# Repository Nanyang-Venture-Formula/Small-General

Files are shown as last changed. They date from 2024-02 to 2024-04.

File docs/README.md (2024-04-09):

# Small General (Rev 4.1)

This repository contains all documents regarding the Small General board.

### Shortcuts
- [Schematics](#Schematics)
- [Assembly](#Assembly)
- [Renders](#Renders)
- [Bom](#Bom)

---

## Schematics



## Assembly




## Renders

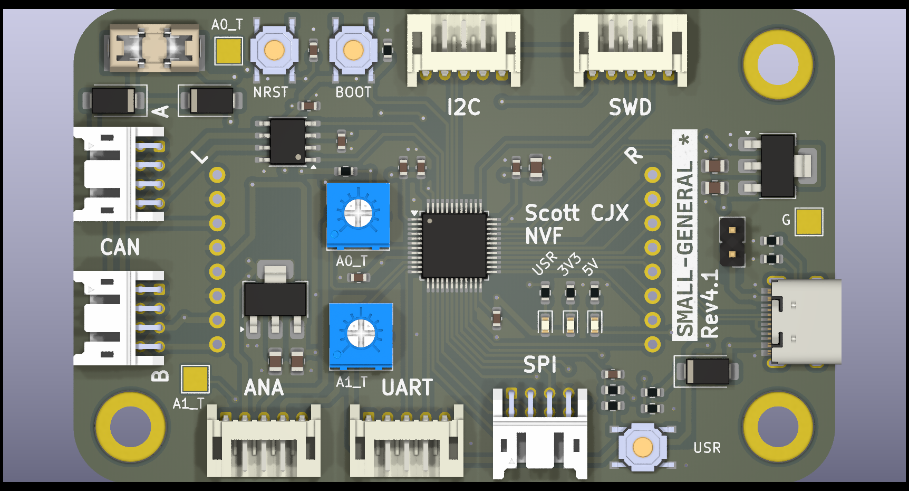
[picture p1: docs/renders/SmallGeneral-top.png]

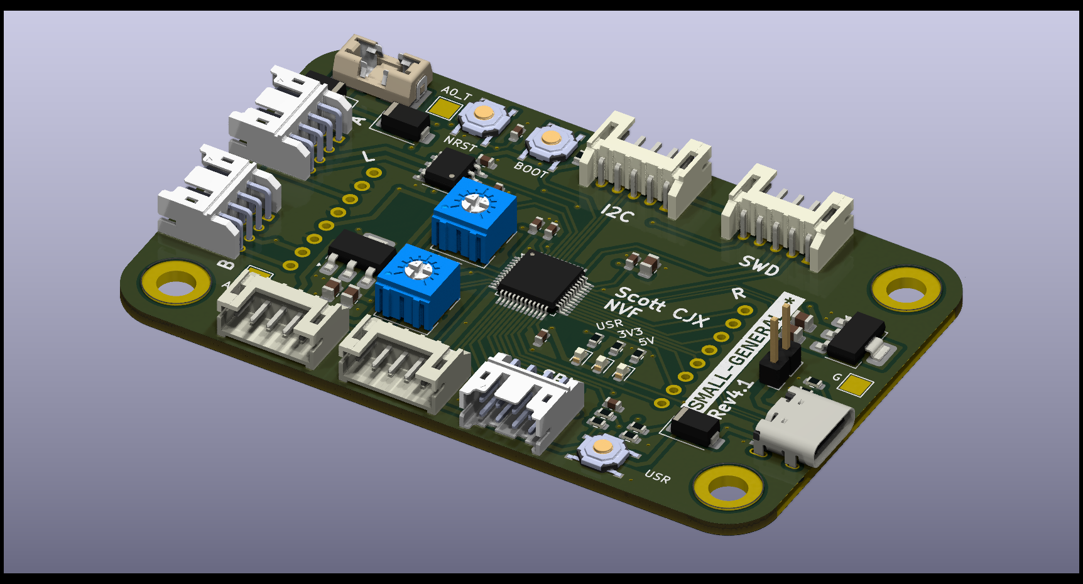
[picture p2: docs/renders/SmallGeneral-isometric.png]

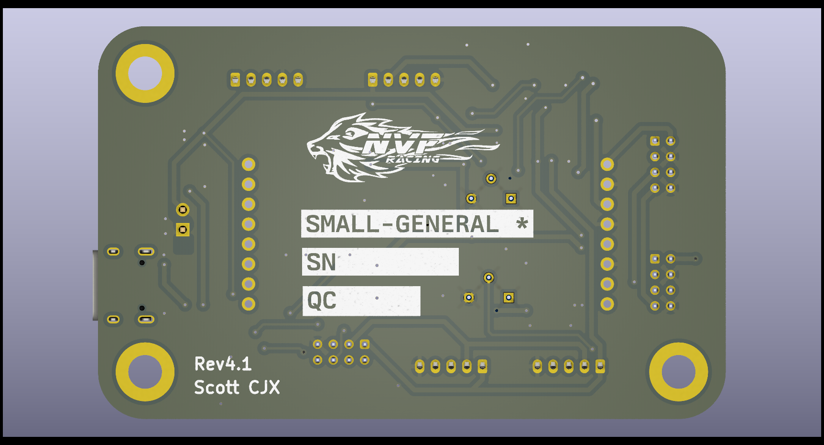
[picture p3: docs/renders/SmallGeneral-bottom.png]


## Bom

[Interactive BOM](./ibom/ibom)

[BOM](./bom/SmallGeneral-BOM.csv)

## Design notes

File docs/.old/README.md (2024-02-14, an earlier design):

# Overview

The Small General is a STM32 based development board that boast a 48MHz Cortex-M0 STM32F072 Microcontroller and breaks out interfaces that a user would usually use when prototyping or for use in small spaces.

### Quick Links

- [Renders](./Renders.md "Renders")
- [Technical](./Technical.md "Technical")

## Form Factor

The Small General is 50mm x 80mm in size.

There are 4 x M4 screw holes (padded top and bottom; connected to ground) that are 6mm x 6mm from the corners of the boards 50mm x 80mm dimensions.

There are 3mm fillets at all 4 corners of the board.

## Features

1. STM32F072CBT6 Microcontroller.
2. USB C (Power & Data)
3. Integrated CanBus. (Multiple Connections)
4. Dual Voltage Regulators for stable 3.3V and 5V supply ( $V_{MAX}$: 20V)
5. Dual trim potentiometers to scale down analog signals before processing + easily accessible testpoints to probe using multimeters.
6. NRST, BOOT0 buttons
7. LED Indicators for 3v3 Power, 5v power
8. Programmble User button and LED

## 5 Pin Connectors:

| Interface | Pin A | Pin B |
| --- | --- | --- |
| ADC | PA0 (A0) | PA1 (A1) |
| UART (UART2) | PA2 (TX) | PA3 (RX) |
| I2C | PB6 (SCL) | PB7 (SDA) |
| SW Debug (SWD) | PA13 (SWDIO) | PA14 (SWCLK) |

Compatible connectors (01x05 Styled - 2.00mm)

- JST PH S5B [Horizontal] (Refer to Parts)
- JST PH B5B [Vertical] (Refer to Parts)

### 8 Pin Connectors:

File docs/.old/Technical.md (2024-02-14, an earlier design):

# Technical

Technical components of the Small General

# LEDs

Calculations for Current Limiting Resistors (CLRs):

Taking into consideration the LED's $V_{F}$ and $I_{F}$, and input Voltage $V_{IN}$:

we can calculate the CLR with the formula $R = \dfrac{(V_{IN}-V_{F})}{I_{F}}$.

### User LED

| Factor | Value |
| --- | ----- |
| $V_{IN}$ | 3.3V  |
| $V_{F}$  | 2.5V  |
| $I_{F}$  | 4mA |

$R = \dfrac{(V_{IN}-V_{F})}{I_{F}} = \dfrac{(3.3-2.5)}{0.004} = 200 \Omega$

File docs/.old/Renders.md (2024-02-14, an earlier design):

# Renders

There are serveral styles of interconnect connectors for the Small General.

- Stacking

  - (Top Female, Bottom Male): Stacking TFBM
- Male Headers

  - (Top Male, Bottom None): TMBN
  - (Top None, Bottom Male): TNBM
- Female Sockets

  - (Top Female, Bottom None): TFBN
  - (Top None, Bottom Female): TNBF
- None

  - (Top None, Bottom None): TNBN

## Stacking TFBM (Top Female, Bottom Male)

TFBM-F

TFBM-I

## TMBN (Top Male, Bottom None)TMBN-F

## TNBN (Top None, Bottom None)

TNBN-F

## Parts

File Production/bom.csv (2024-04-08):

Designator | Footprint | Quantity | Value | LCSC Part #
C101 | 0805 | 1 | 4u7 | C1779
C102, C103, C104, C105, C106, C107, C108, C109, C110 | 0603 | 9 | 100n | C14663
C111, C112, C113, C114 | 0805 | 4 | 2u2 | C377773
D101 | 0603 | 1 | GREEN | C434423
D102 | 0603 | 1 | RED | C2286
D103 | 0603 | 1 | BLUE | C965807
D104, D105, D106 | D_SMA | 3 | SS14 | C2480
F101 | FUSE-Littelfuse_Nano2_154x | 1 | Fuse | C206919
J101 | USBC_HRO_TYPE-C-31-M-12 | 1 | USB_C | C165948
JP101 | PinHeader_1x02_P2.54mm_Vertical | 1 | Jumper_2_Open | -
R101, R102, R103, R110 | 0603 | 4 | 10k | C25804
R104, R111 | 0603 | 2 | 1k | C21190
R105, R106, R107 | 0603 | 3 | 300 | C23025
R108, R109 | 0603 | 2 | 5k1 | C23186
RV101, RV102 | RV_Bourns_3362 | 2 | 10k | C58159
SG101 | Small-General Actual | 1 | ~ | -
SW101, SW102, SW103 | PushBtn_TS-1187A-B-A-B | 3 | SW_Push | C318884
TP101, TP102, TP103 | TestPoint_Pad_2.5x2.5mm | 3 | TestPoint | -
U101 | LQFP-48_7x7mm_P0.5mm | 1 | STM32F072CBT6 | C81720
U102 | SOIC-8_3.9x4.9mm_P1.27mm | 1 | TJA1042T-3 | C132227
U103 | SOT-223-3_TabPin2 | 1 | AMS1117-3.3 | C6186
U104 | SOT-223-3_TabPin2 | 1 | AMS1117-5.0 | C6187

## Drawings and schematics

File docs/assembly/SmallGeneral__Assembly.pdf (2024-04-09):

### BOARD CHARACTERISTICS

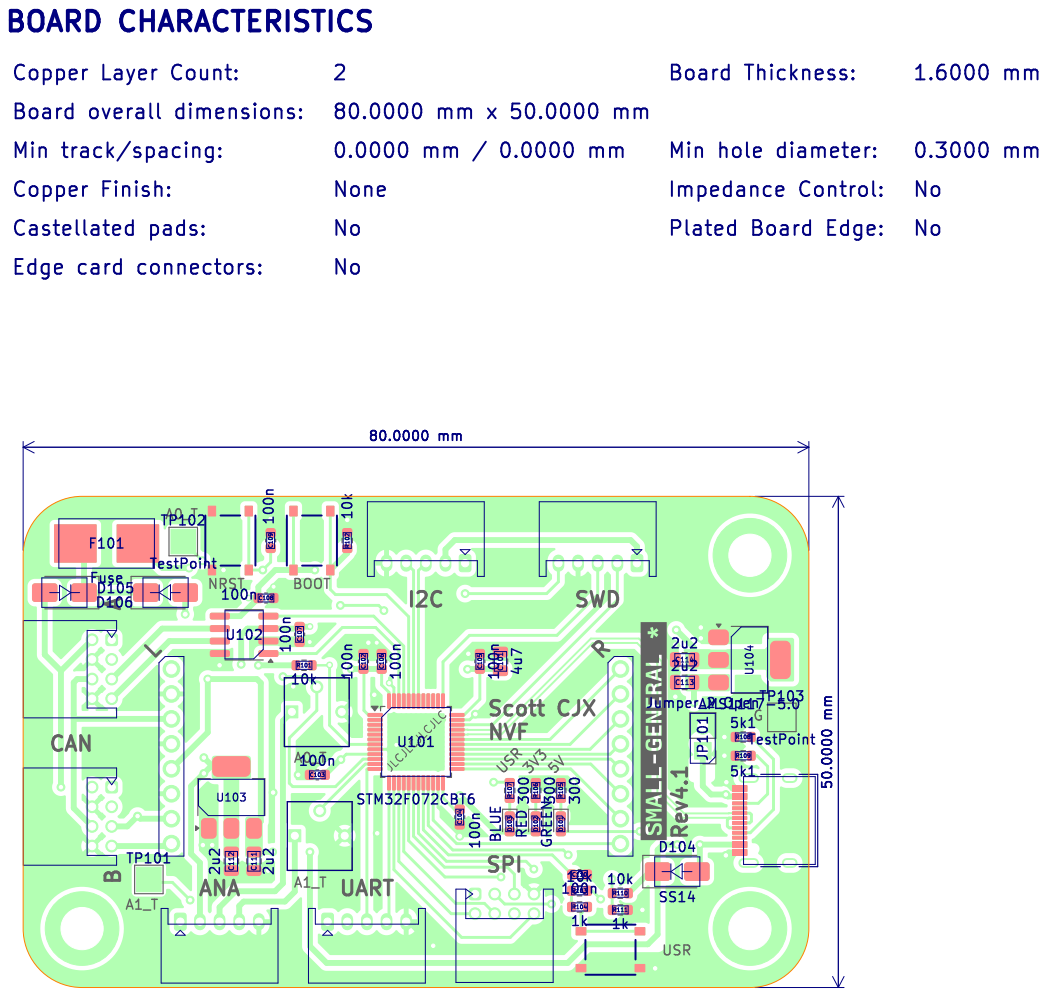
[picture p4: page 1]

Id: 1/1 Title: Small General File: SmallGeneral.kicad_pcb Sheet: Scott CJX

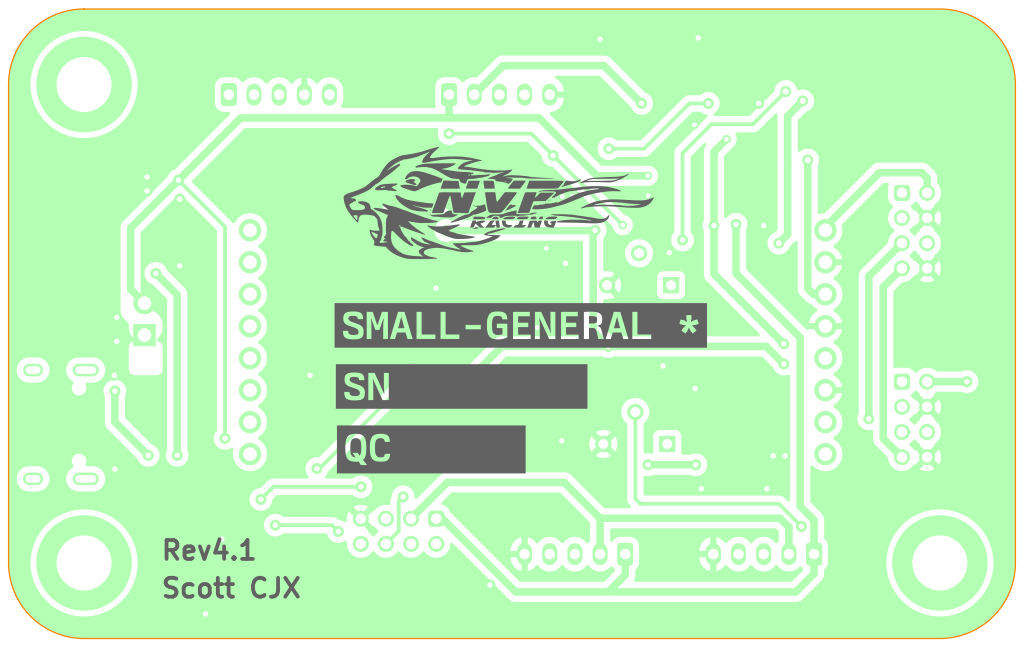
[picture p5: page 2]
Rev4.1 Scott CJX; D Date: 2024-04-08 KiCad; E.D.A. 8.0.1 Size: A4; Rev: 4.1

Id: 1/1 Title: Small General File: SmallGeneral.kicad_pcb Sheet: Scott CJX

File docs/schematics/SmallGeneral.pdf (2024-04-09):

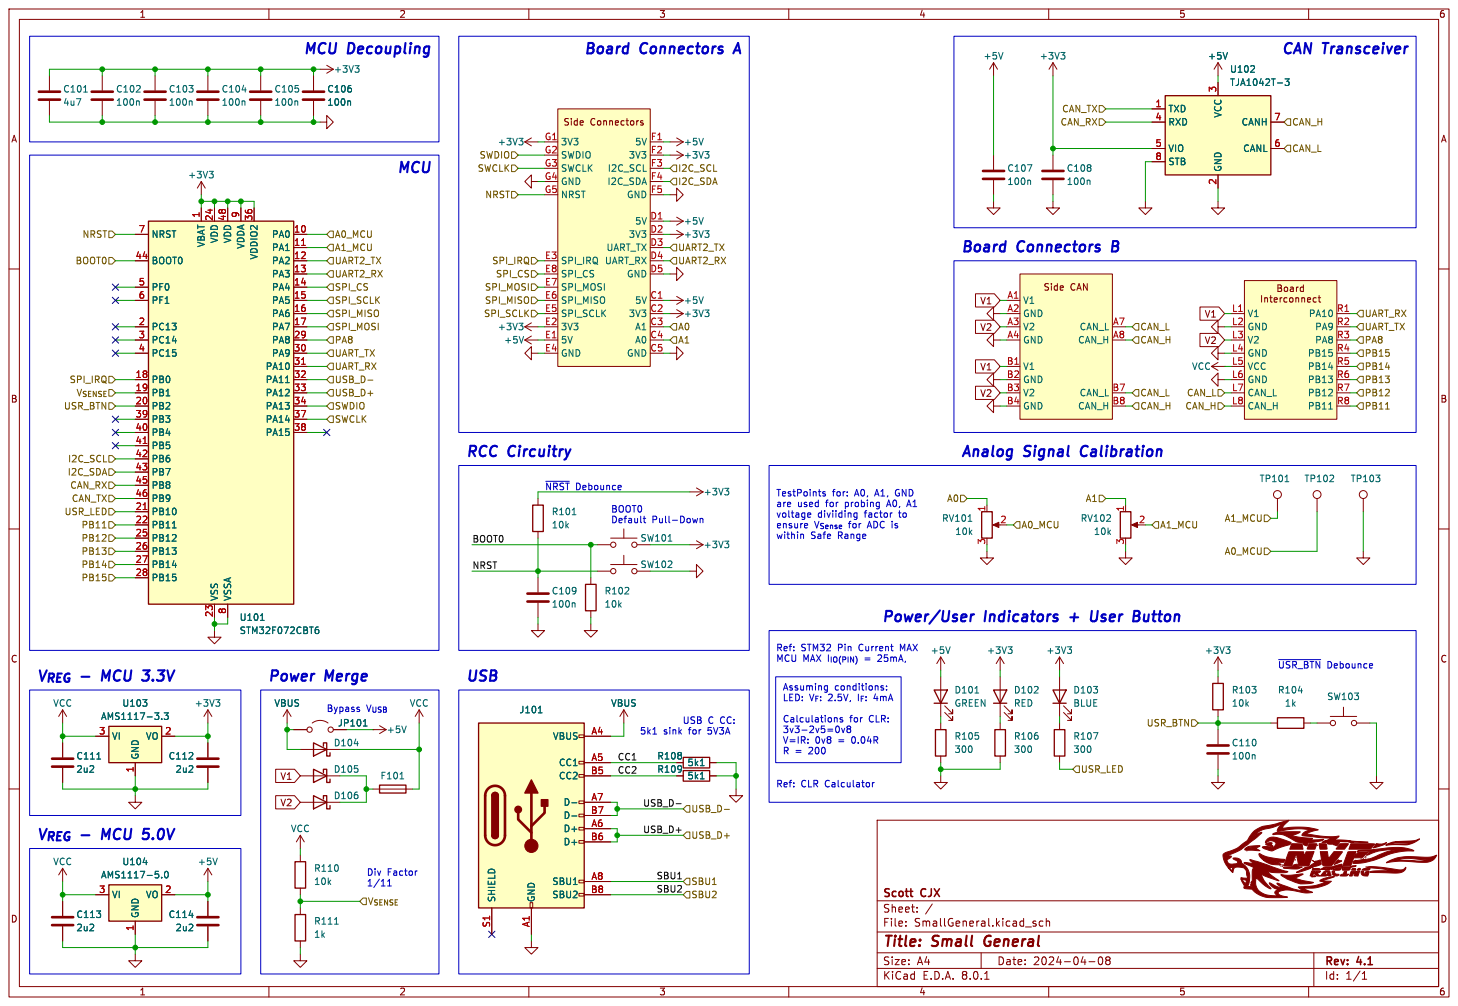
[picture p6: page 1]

3 RXD 4 VIO 5 CANL 6 CANH 7 STB 8 +5V C106

3 RXD 4 VIO 5 CANL 6 CANH 7 STB 8 U102 TJA1042T-3 C108

1 PA0 10 PA1 11 PA2 12 PA3 13 PA4 14 PA5 15 PA6 16 PA7 17 PB0 18 PB1 19 PC13 2 PB2 20 PB10 21 PB11 22 VSS 23 VDD 24 PB12 25 PB13 26 PB14 27 PB15 28 PA8 29 PC14 3 PA9 30 PA10 31 PA11 32 PA12 33 PA13 34 VDDIO2 36 PA14 37 PA15 38 PB3 39 PC15 4 PB4 40 PB5 41 PB6 42 PB7 43 BOOT0 44 PB8 45 PB9 46 VDD 48 PF0 5 PF1 6 NRST 7 VSSA
BOOT0 V_{SENSE} USR_BTN

~{USR_BTN}Debounce USB C CC: 5k1 sink for 5V3A RCC Circuitry

are used for probing A0, A1
ensure V_{Sense} for ADC is within Safe Range

R = 200 Ref: CLR Calculator V_{REG} - MCU 5.0V

Id: 1/1 Title: Small General File: SmallGeneral.kicad_sch Sheet: / Scott CJX

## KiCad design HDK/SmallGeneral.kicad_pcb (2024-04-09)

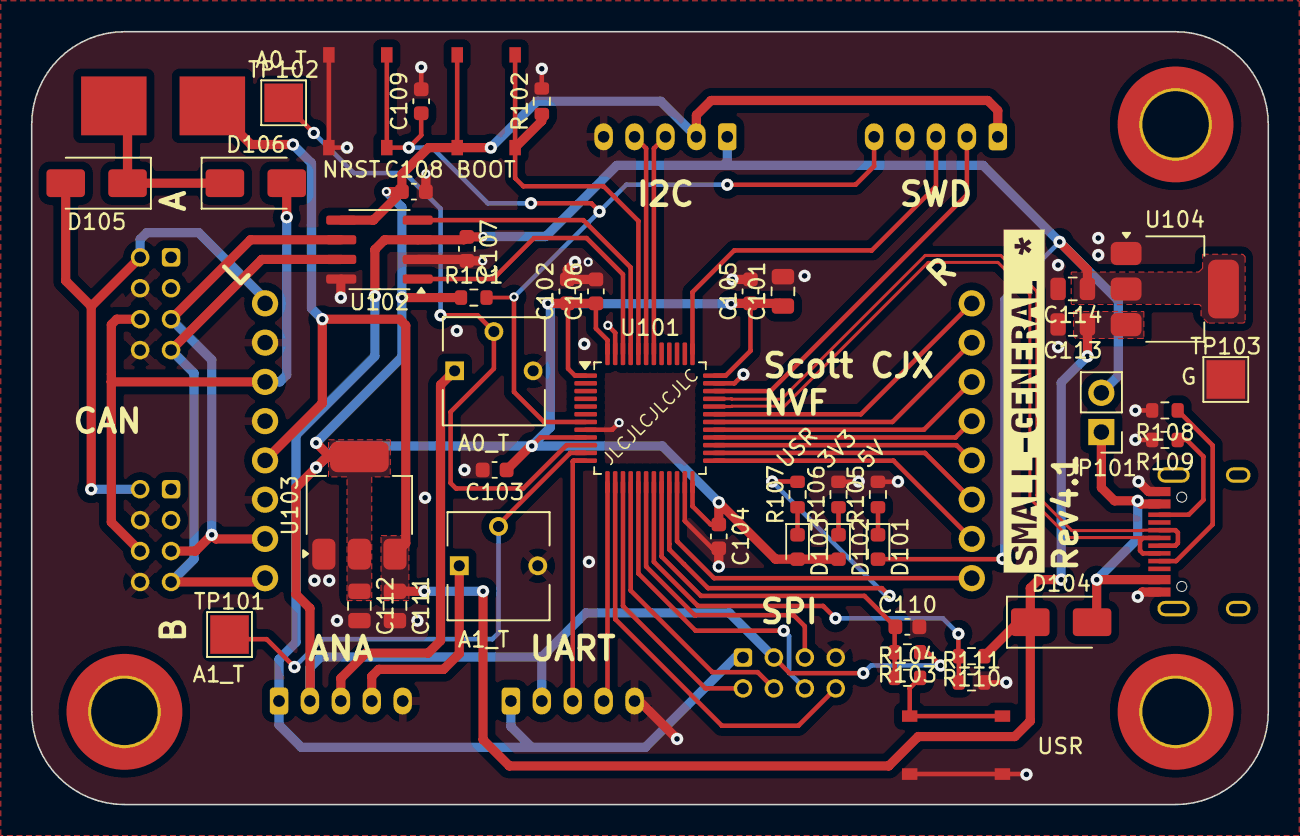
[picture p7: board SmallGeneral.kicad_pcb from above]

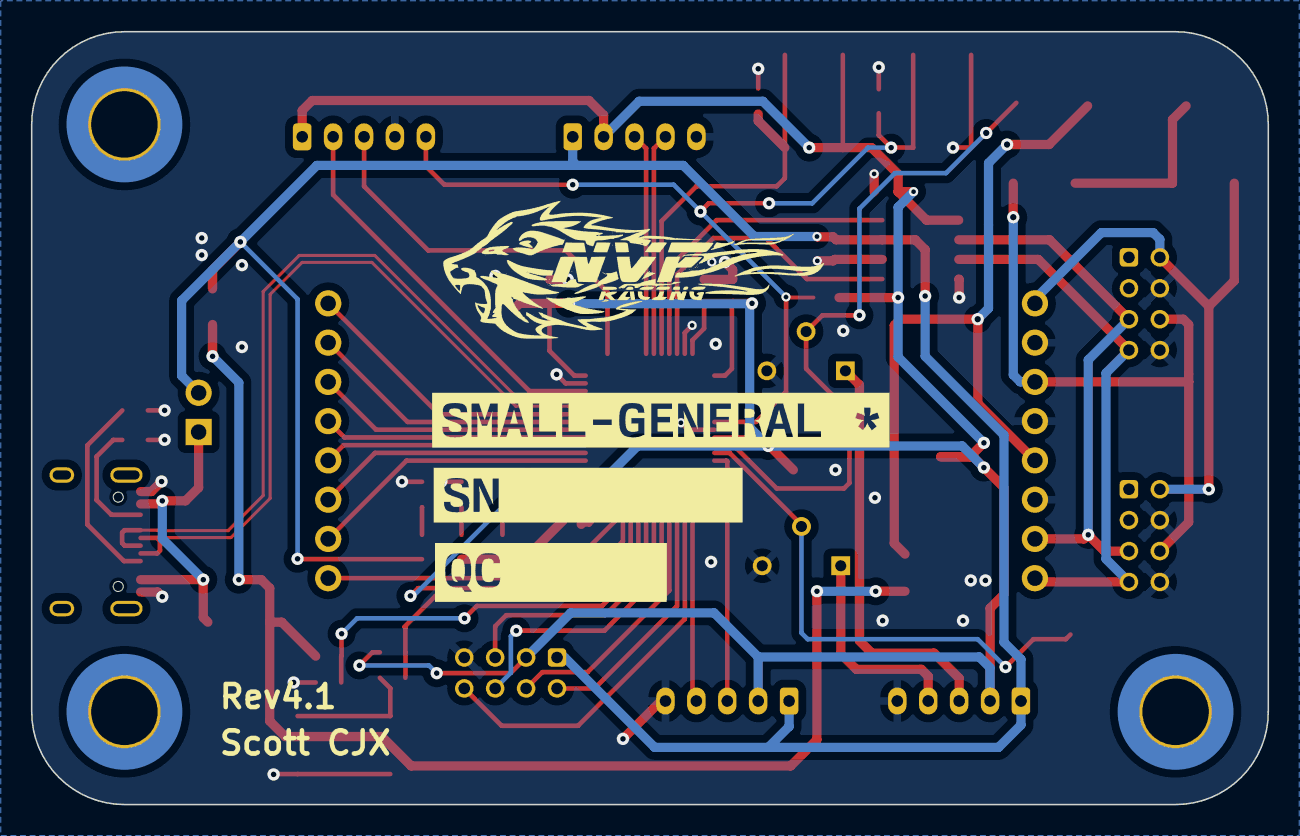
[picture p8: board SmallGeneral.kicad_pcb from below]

Board: 2 copper layers, 80.0 x 50.0 mm, 51 parts (3 on the bottom side), 48 nets.

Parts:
C101: 4u7; C_0805_2012Metric
C102, C103, C104, C105, C106, C107, C108, C109, C110: 100n; C_0603_1608Metric
C111, C112, C113, C114: 2u2; C_0805_2012Metric
D101: GREEN; LED_0603_1608Metric
D102: RED; LED_0603_1608Metric
D103: BLUE; LED_0603_1608Metric
D104, D105, D106: SS14; D_SMA
F101: Fuse; FUSE-Littelfuse_Nano2_154x
J101: USB_C; USBC_HRO_TYPE-C-31-M-12
JP101: Jumper_2_Open; PinHeader_1x02_P2.54mm_Vertical
R101, R102, R103, R110: 10k; R_0603_1608Metric
R104, R111: 1k; R_0603_1608Metric
R105, R106, R107: 300; R_0603_1608Metric
R108, R109: 5k1; R_0603_1608Metric
RV101, RV102: 10k; RV_Bourns_3362
SG101: Small-General Actual
SW101, SW102, SW103: SW_Push; PushBtn_TS-1187A-B-A-B
TP101, TP102, TP103: TestPoint; TestPoint_Pad_2.5x2.5mm
U101: STM32F072CBT6; LQFP-48_7x7mm_P0.5mm
U102: TJA1042T-3; SOIC-8_3.9x4.9mm_P1.27mm
U103: AMS1117-3.3; SOT-223-3_TabPin2
U104: AMS1117-5.0; SOT-223-3_TabPin2
kibuzzard-65C10821: G***; kibuzzard-65C10821
kibuzzard-65C10836: G***; kibuzzard-65C10836
kibuzzard-65CCCADD: G***; kibuzzard-65CCCADD
kibuzzard-65CCCB35: G***; kibuzzard-65CCCB35

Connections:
+3V3: C101.1, C102.1, C103.1, C104.1, C105.1, C106.1, C108.1, C112.1, D102.2 (A), D103.2 (A), R101.1, R103.1, SG101.C2 (3V3), SG101.D2 (3V3), SG101.E2 (3V3), SG101.F2 (3V3), SG101.G1 (3V3), SW101.2, U101.1 (VBAT), U101.9 (VDDA), U101.24 (VDD), U101.36 (VDDIO2), U101.48 (VDD), U102.5 (VIO), U103.2 (VO)
+5V: C107.1, C114.1, D101.2 (A), JP101.2 (B), SG101.C1 (5V), SG101.D1 (5V), SG101.E1 (5V), SG101.F1 (5V), U102.3 (VCC), U104.2 (VO)
/A0: RV101.1, SG101.C3 (A1)
/A0_MCU: RV101.2, TP102.1, U101.10 (PA0)
/A1: RV102.1, SG101.C4 (A0)
/A1_MCU: RV102.2, TP101.1, U101.11 (PA1)
/BOOT0: R102.1, SW101.1, U101.44 (BOOT0)
/CAN_H: SG101.A8 (CAN_H), SG101.B8 (CAN_H), SG101.L8 (CAN_H), U102.7 (CANH)
/CAN_L: SG101.A7 (CAN_L), SG101.B7 (CAN_L), SG101.L7 (CAN_L), U102.6 (CANL)
/CAN_RX: U101.45 (PB8), U102.4 (RXD)
/CAN_TX: U101.46 (PB9), U102.1 (TXD)
/CC1: J101.A5 (CC1), R108.1
/CC2: J101.B5 (CC2), R109.1
/I2C_SCL: SG101.F3 (I2C_SCL), U101.42 (PB6)
/I2C_SDA: SG101.F4 (I2C_SDA), U101.43 (PB7)
/NRST: C109.1, R101.2, SG101.G5 (NRST), SW102.1, U101.7 (NRST)
/PA8: SG101.R3 (PA8), U101.29 (PA8)
/PB11: SG101.R8 (PB11), U101.22 (PB11)
/PB12: SG101.R7 (PB12), U101.25 (PB12)
/PB13: SG101.R6 (PB13), U101.26 (PB13)
/PB14: SG101.R5 (PB14), U101.27 (PB14)
/PB15: SG101.R4 (PB15), U101.28 (PB15)
/SPI_CS: SG101.E8 (SPI_CS), U101.14 (PA4)
/SPI_IRQ: SG101.E3 (SPI_IRQ), U101.18 (PB0)
/SPI_MISO: SG101.E6 (SPI_MISO), U101.16 (PA6)
/SPI_MOSI: SG101.E7 (SPI_MOSI), U101.17 (PA7)
/SPI_SCLK: SG101.E5 (SPI_SCLK), U101.15 (PA5)
/SWCLK: SG101.G3 (SWCLK), U101.37 (PA14)
/SWDIO: SG101.G2 (SWDIO), U101.34 (PA13)
/UART2_RX: SG101.D4 (UART_RX), U101.13 (PA3)
/UART2_TX: SG101.D3 (UART_TX), U101.12 (PA2)
/UART_RX: SG101.R1 (PA10), U101.31 (PA10)
/UART_TX: SG101.R2 (PA9), U101.30 (PA9)
/USB_D+: J101.A6 (D+), J101.B6 (D+), U101.33 (PA12)
/USB_D-: J101.A7 (D-), J101.B7 (D-), U101.32 (PA11)
/USR_BTN: C110.1, R103.2, R104.1, U101.20 (PB2)
/USR_LED: R107.2, U101.21 (PB10)
/V_{SENSE}: R110.2, R111.1, U101.19 (PB1)
GND: C101.2, C102.2, C103.2, C104.2, C105.2, C106.2, C107.2, C108.2, C109.2, C110.2, C111.2, C112.2, C113.2, C114.2, J101.A1 (GND), J101.A12 (GND), J101.B1 (GND), J101.B12 (GND), R102.2, R105.2, R106.2, R108.2, R109.2, R111.2, RV101.3, RV102.3, SG101.A2 (GND), SG101.A4 (GND), SG101.B2 (GND), SG101.B4 (GND), SG101.C5 (GND), SG101.D5 (GND), SG101.E4 (GND), SG101.F5 (GND), SG101.G4 (GND), SG101.L2 (GND), SG101.L4 (GND), SG101.L6 (GND), SW102.2, SW103.2, TP103.1, U101.8 (VSSA), U101.23 (VSS), U101.35 (VSS), U101.47 (VSS), U102.2 (GND), U102.8 (STB), U103.1 (GND), U104.1 (GND)
unnamed: D101.1 (K), R105.1
unnamed: D102.1 (K), R106.1
unnamed: D103.1 (K), R107.1
unnamed: D105.1 (K), D106.1 (K), F101.1
unnamed: R104.2, SW103.1
V1: D105.2 (A), SG101.A1 (V1), SG101.B1 (V1), SG101.L1 (V1)
V2: D106.2 (A), SG101.A3 (V2), SG101.B3 (V2), SG101.L3 (V2)
VBUS: D104.2 (A), J101.A4 (VBUS), J101.A9 (VBUS), J101.B4 (VBUS), J101.B9 (VBUS), JP101.1 (A)
VCC: C111.1, C113.1, D104.1 (K), F101.2, R110.1, SG101.L5 (VCC), U103.3 (VI), U104.3 (VI)

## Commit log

2024-02-05 added rev1
    [SmallGeneral.kicad_pcb, SmallGeneral.kicad_sch, bom.csv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]
2024-02-14 updated rev3
    [SmallGeneral.kicad_pcb, SmallGeneral.kicad_sch]
2024-02-14 updated Trim Pot Switch
    [SmallGeneral.kicad_pcb, SmallGeneral.kicad_sch]
2024-02-14 fixed rev3 switch
2024-03-17 updated docs
    [SmallGeneral.kicad_pcb, SmallGeneral.kicad_sch, bom.csv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]
2024-03-18 added docs
    [SmallGeneral.kicad_pcb, bom.csv, designators.csv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]
2024-04-08 updated rev4
    [SmallGeneral-B_Adhesive.gbr, SmallGeneral-B_Cu.gbr, SmallGeneral-B_Mask.gbr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]
2024-04-08 updated rev4.1
    [SmallGeneral-B_Adhesive.gbr, SmallGeneral-B_Cu.gbr, SmallGeneral-B_Mask.gbr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]
2024-04-08 added prod and ibom
    [bom.csv, designators.csv, positions.csv]
2024-04-08 updated schematics
2024-04-08 fixed schematics
2024-04-09 updated correct gerbers
    [SmallGeneral.kicad_pcb]
